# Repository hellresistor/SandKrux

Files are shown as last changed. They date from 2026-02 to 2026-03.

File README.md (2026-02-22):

# SandKrux

Placa de desenvolvimento baseada no chip **K210**, com entradas para **touch**, **câmera** e **LCD grande**, criada especificamente para rodar o firmware **Krux**.

## Status do projeto
**Em desenvolvimento — não finalizado.**  
Este repositório está em evolução. Mudanças podem ocorrer sem aviso.

## Foto da placa
Coloque a imagem em `docs/placa.jpg` (ou ajuste o caminho abaixo).

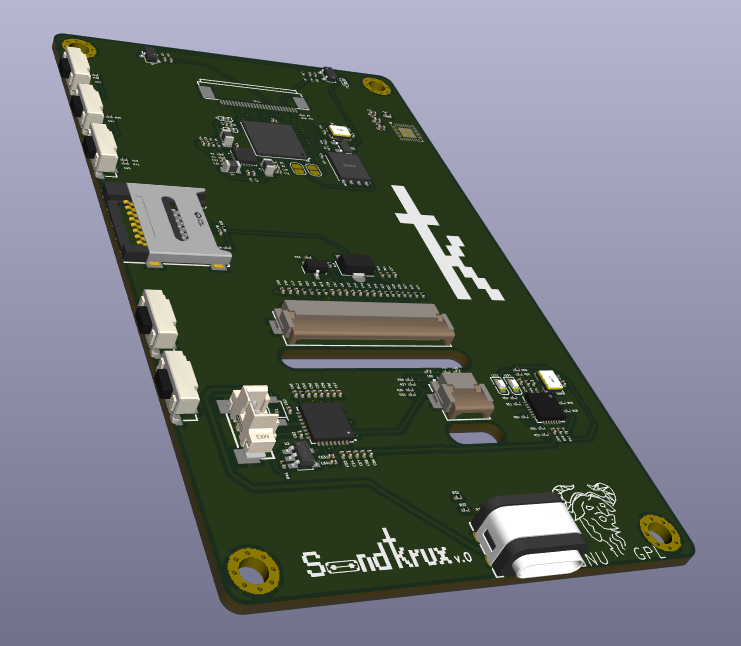
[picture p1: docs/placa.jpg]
Foto da placa


## Firmware alvo
Este hardware está sendo desenvolvido para o firmware Krux:
- https://github.com/selfcustody/krux

## Como colaborar
Contribuições da comunidade são muito bem-vindas.  
Abra issues, discuta melhorias e proponha alterações.

## Licença
GPLv3.

## Nota sobre fabricação e apoio ao Krux
Se no futuro você pretender **fabricar e vender** este dispositivo, fica o pedido de doar **ao menos 1%** do valor dos dispositivos para a equipe de desenvolvimento do Krux.  
Este é um projeto open-source e, sem o trabalho deles, nada disso existiria.

## Agradecimentos
Obrigado à comunidade e à equipe do Krux pelo trabalho que torna este projeto possível.

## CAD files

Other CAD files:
LIB_SandKrux/LIB_FH12-40S-0.5SH_55_/FH12-40S-0.5SH_55_/Allegro/fh1240s05sh55.psm
LIB_SandKrux/LIB_FH12-40S-0.5SH_55_/FH12-40S-0.5SH_55_/DEHDL/fh12_40s_0.5sh_55_/chips/chips.prt

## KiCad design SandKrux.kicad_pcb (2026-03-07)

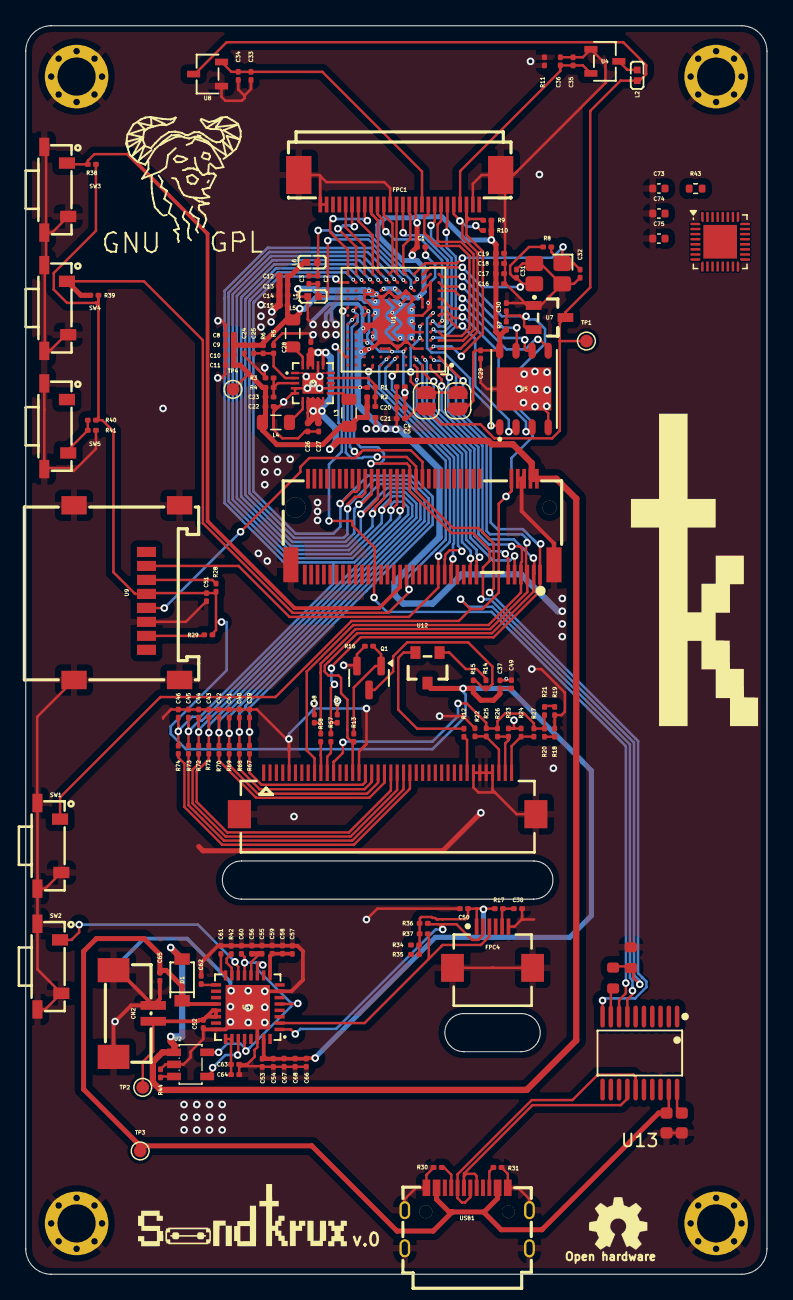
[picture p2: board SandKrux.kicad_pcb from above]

Board: 2 copper layers, 58.3 x 98.2 mm, 170 parts (0 on the bottom side), 115 nets.

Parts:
C1, C60, C62: 1uF; C_0201_0603Metric
C2, C4, C5, C6, C7, C18, C19, C29, C30, C34, C38, C49, C56: 100nF; C_0201_0603Metric
C3, C8, C9, C10, C11, C12, C13, C14, C15, C16, C17, C33, C36, C37, C50, C51, C53, C55, C58, C65: 10uF; C_0201_0603Metric
C20, C23, C25: 18pF; C_0201_0603Metric
C21, C22, C24, C26, C27, C28, C35, C52, C57, C59, C64, C66, C67, C68: 22uF; C_0201_0603Metric
C31, C32: 6pF; C_0201_0603Metric
C39, C40, C41, C42, C43, C44, C45, C46, C47, C48: 100pF; C_0201_0603Metric
C54: 1nF; C_0201_0603Metric
C61: 220uF; C_0201_0603Metric
C63: 220nF; C_0201_0603Metric
C73, C74, C75: 100n; C_0402_1005Metric
C77: 22uF; C_0603
C79: 10uF; C_0603
CN2: 1.25mm-2P socket; CONN-SMD_1.25T-2P
D1: 1N5819HW-7-F; SOD-123_L2.7-W1.6-LS3.7-RD
FPC1: 05A20L26P; FPC-SMD_05A20L26P
FPC3: FH12-40S-0.5SH(55); FPC-SMD_FH12-40S-0.5SH-55
FPC4: FH12-6S-0.5SH(55); FPC-SMD_FH12-6S-0.5SH-55
H1, H2, H3, H4: Hole, 3mm
IC1: TROPIC01_chip; QFN-32-1EP_4x4mm_P0.4mm_EP2.65x2.65mm
JP1, JP2: SolderJumper_2_Open; SolderJumper-2_P1.3mm_Open_RoundedPad1.0x1.5mm
L1, L2, L6: CBW100505U601T; L0402
L3, L4, L5: 2.2uH; L_0805_2012Metric
Q1: S8050; Q_SOT-23
R1, R6: 300k 1%; R_0201_0603Metric
R2, R3, R5: 150k 1%; R_0201_0603Metric
R4: 680k 1%; R_0201_0603Metric
R7: 12K; R_0201_0603Metric
R8: 1M; R_0201_0603Metric
R9, R10: 2K; R_0201_0603Metric
R11, R18, R21, R41: 0R; R_0201_0603Metric
R12: 5.1R; R_0201_0603Metric
R13, R14, R57, R58, R67, R68, R69, R70, R71, R72, R73, R74: 100R; R_0201_0603Metric
R15, R16, R17, R28, R29, R44: 10K; R_0201_0603Metric
R19, R20, R22, R23, R27, R40: NC; R_0201_0603Metric
R24, R25, R26, R30, R31: 5.1K; R_0201_0603Metric
R32, R33: 1kΩ; R_0603
R34, R35, R36, R37, R38, R39: 1.5K; R_0201_0603Metric
R42: 200K; R_0201_0603Metric
R43: 47k; R_0402_1005Metric
SW1, SW2, SW3, SW4, SW5: TL3330AF130QG; SW-SMD_E-SWITCH_TL3330
Sign_OSHW_7.3x6.0mm: Sign_OSHW_7.3x6.0mm; Sign_OSHW_7.3x6.0mmn
TP1, TP2, TP3, TP4: TestPoint_Small; TestPoint_Pad_D1.0mm
U1: K210_C913414; BGA-144_L8.0-W8.0-R12-C12-P0.65-BL
U2: MT9700; SOT-23-5_L3.0-W1.7-P0.95-LS2.8-BR
U3: XC6206-3.3V; SSOT-3_L2.9-W1.6-P0.95-LS2.8-BR
U4: XC6206P182MR_C347373; SOT-23-3_L3.0-W1.7-P0.95-LS2.9-BR
U5: GD25LQ128EWIGR; WSON-8_L6.0-W5.0-P1.27-BL-EP
U6: TMI7003C; QFN-20_L3.0-W3.0-P0.40-BL-EP1.7
U7: SGM803-TXN3/TR_C5152602; SOT-23-3_L2.9-W1.5-P1.90-LS2.6-BR
U8: XC6206P302MR_C347375; SOT-23-3_L3.0-W1.7-P0.95-LS2.9-BR
U9: HX TF-CARD XG8P H1.5; TF-SMD_HX-TF-CARD-XG8P-H1.5
U10: AXP173_C3345106; QFN-32_L5.0-W5.0-P0.50-TL-EP3.5-1
U12: PCIE-67P42H; PCIE-SMD_75P-P0.50_HYC01B-05NGFF-420
U13: CH552T; TSSOP-20_L6.5-W4.4-P0.65-LS6.4-BL
USB1: HYCW412-USBC16-065B; USB-C-SMD_HYCW412-USBC16-065B
X1: X322526MMB4SI; CRYSTAL-SMD_4P-L3.2-W2.5-BL

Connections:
+3.3V: C4.2, C5.2, C6.2, C7.2, JP2.1 (A), L2.2, TP1.1, U1.C5 (VDDIO5B), U1.C7 (VDDIO4B), U1.C8 (VDDIO3B), U1.D10 (VDDIO2A), U1.G10 (VDDIO1A), U1.H10 (VDDIO0A), U7.3 (VCC), U8.3 (VIN)
/3V3: C37.1, C49.1, C50.1, C51.2, C53.2, C54.2, C66.2, C67.2, C68.2, FPC4.1, R15.2, R17.1, R28.2, R29.2, R34.2, R35.2, R36.1, R37.1, R38.1, R39.1, R40.2, U3.3 (VIN), U9.4 (VDD), U10.31 (DCDC1)
/5V: C26.2, C27.2, C28.2, D1.2 (A), U2.1 (VOUT), U6.7 (VIN2), U6.8 (EN2), U6.9 (EN1), U6.10 (VIN1), U6.16 (NC), U6.18 (EN3), U6.19 (VIN3), U12.2, U12.4
/5V_USB: C65.1, C79.1, D1.1 (K), TP3.1, U10.20 (ACIN), U13.19 (VCC/VDD), USB1.A4B9 (VBUS), USB1.B4A9 (VBUS)
/ADD_3V0: C57.2, C58.2, C59.2, U10.9 (LDO3)
/BOOT: U1.B12 (IO_16), U12.53, U13.8 (P1.1/T2EX/CAP2/TIN1/VBUS2/AIN0)
/CAPTOUCH_RST: C38.1, FPC4.5, R17.2
/CC1_2: R30.2, USB1.A5 (CC1)
/CC2_2: R31.2, USB1.B5 (CC2)
/CH552_P1.0: C30.2, R7.2, SW1.1, U1.M1 (~RESET), U7.2 (~RESET), U12.10, U13.7 (P1.0/T2/CAP1/TIN0)
/CH552_RX0: U1.H12 (IO_5), U12.40, U13.10 (P3.0/PWM1_/RXD)
/CH552_TX0: R32.1, U13.9 (P3.1/PWM2_/TXD)
/EXTEN: U2.4 (EN), U10.27 (EXTEN)
/I2C_SCL: FPC4.3, R37.2, U10.2 (SCK)
/I2C_SDA: FPC4.2, R36.2, U10.1 (SDA)
/I2S2_SDI: U1.A3 (IO_35), U12.11
/I2S2_SDOD: U1.B3 (IO_34), U12.9
/IM0: FPC3.38, R22.1, R25.1
/IM1: FPC3.39, R23.1, R26.1
/IM2: FPC3.40, R24.1, R27.1
/IPSOUT: C60.1, U2.5 (VIN), U10.5 (VIN2), U10.11 (LDOIN), U10.13 (APS), U10.28 (VIN1)
/ISET: R44.2, U2.3 (SET)
/ISP_RX: R32.2, R33.1, U1.H11 (IO_4), U12.42
/KEY1: R39.2, SW4.1, U1.A9 (IO_23), U12.43
/KEY2: R38.2, SW3.1, U12.45
/LCD_BACKLIGHT: R12.2, U3.2 (VOUT)
/LCD_CS: FPC3.9, U1.A2 (IO_36), U12.7
/LCD_D0: C39.1, R67.2, U1.L12 (SPI0_D0), U12.58
/LCD_D1: C40.1, R68.2, U1.L11 (SPI0_D1), U12.56
/LCD_D2: C41.1, R69.2, U1.L10 (SPI0_D2), U12.54
/LCD_D3: C42.1, R70.2, U1.L9 (SPI0_D3), U12.52
/LCD_D4: C43.1, R71.2, U1.L8 (SPI0_D4), U12.50
/LCD_D5: C44.1, R72.2, U1.L7 (SPI0_D5), U12.48
/LCD_D6: C45.1, R73.2, U1.L6 (SPI0_D6), U12.46
/LCD_D7: C46.1, R74.2, U1.L5 (SPI0_D7), U12.44
/LCD_DC: C48.1, R58.2, U1.B2 (IO_38), U12.5
/LCD_RST: FPC3.15, R13.1, U1.A1 (IO_37), U12.3
/LCD_WR: C47.1, R57.2, U1.B1 (IO_39), U12.1
/PIN21: U1.B4 (IO_32), U12.21
/PIN23: U1.A4 (IO_33), U12.23
/PWRON: SW2.1, U10.14 (PWRON)
/SPI1_CS_TF: U1.B7 (IO_26), U9.2 (CD/DAT3), U12.33
/SPI1_MISO: U1.G11 (IO_6), U9.5 (CLK), U12.38
/SPI1_MOSI: R28.1, U9.3 (CMD)
/USBDM: U13.15 (P3.7/UDM), USB1.A7 (DN1), USB1.B7 (DN2)
/USBDP: U13.14 (P3.6/UDP), USB1.A6 (DP1), USB1.B6 (DP2)
/USB_D+: U1.B6 (IO_28), U12.29
/USB_D-: U1.A6 (IO_29), U12.31
/VBAT: C52.2, CN2.1, TP2.1, U10.21 (BAT), U10.22 (BAT)
/VCC_1V83V3: FPC3.12, R20.2, R21.2, R25.2, R26.2, R27.2
/VCC_6: R18.1, R20.1
/VCC_7: R19.1, R21.1
/VDD: C55.1, C56.1, U10.12 (LDO4)
/k210/0V9: C8.2, C9.2, C10.2, C11.2, C12.2, C13.2, C14.2, C15.2, C20.2, C21.2, C22.2, C23.2, C24.2, C25.2, L3.1, L4.1, L5.1, L6.2, R2.1, R4.1, R6.1, TP4.1, U1.D4 (VDD), U1.D6 (VDD), U1.D9 (VDD), U1.E7 (VDD), U1.E9 (VDD), U1.F4 (VDD), U1.F6 (VDD), U1.G7 (VDD), U1.G9 (VDD), U1.H4 (VDD), U1.H6 (VDD), U1.J5 (VDD), U1.J7 (VDD), U1.J9 (VDD)
/k210/1V8: C1.1, C16.2, C17.2, C18.2, C19.2, C29.1, FPC1.11, JP1.2 (B), R7.1, R9.2, R10.2, U1.H3 (VDDIO18), U1.J3 (VDDOTP), U1.K6 (VDDIO18), U1.K8 (VDDIO18), U5.8 (VCC)
/k210/26M_OUT: U1.L3 (OSC_CLK), U1.M2 (CLK)
/k210/CMOS-AVDD: C35.2, C36.2, FPC1.4, U4.2 (VOUT)
/k210/CMOS-DVDD: C33.2, C34.2, FPC1.10, U8.2 (VOUT)
/k210/DVP_D0: FPC1.19, U1.M12 (DVP_D0)
/k210/DVP_D1: FPC1.21, U1.M11 (DVP_D1)
/k210/DVP_D2: FPC1.22, U1.M10 (DVP_D2)
/k210/DVP_D3: FPC1.20, U1.M9 (DVP_D3)
/k210/DVP_D4: FPC1.18, U1.M8 (DVP_D4)
/k210/DVP_D5: FPC1.16, U1.M7 (DVP_D5)
/k210/DVP_D6: FPC1.14, U1.M6 (DVP_D6)
/k210/DVP_D7: FPC1.12, U1.M5 (DVP_D7)
/k210/DVP_HSYNC: FPC1.9, U1.E1 (IO_45)
/k210/DVP_PCLK: FPC1.17, U1.F1 (IO_47)
/k210/DVP_PWDN: FPC1.8, U1.E2 (IO_44)
/k210/DVP_RST: FPC1.6, U1.D2 (IO_42)
/k210/DVP_SCL: FPC1.5, R10.1, U1.C1 (IO_41)
/k210/DVP_SDA: FPC1.3, R9.1, U1.C2 (IO_40)
/k210/DVP_VSYNC: FPC1.7, U1.D1 (IO_43)
/k210/DVP_XCLK: FPC1.13, U1.F2 (IO_46)
/k210/F_CLK: U1.K1 (F_CLK), U5.6 (SCLK)
/k210/F_CS: U1.G2 (F_CS), U5.1 (~CS)
/k210/F_D0: U1.J1 (F_D0), U5.5 (SI(IO0))
/k210/F_D1: U1.G1 (F_D1), U5.2 (SO(IO1))
/k210/F_D2: U1.H1 (F_D2), U5.3 (WP#(IO2))
/k210/F_D3: U1.L1 (F_D3), U5.7 (HOLD#(IO3))
/k210/Vadj: C20.1, R1.1, R2.2, U6.14 (FB1)
/k210/Vb: JP1.1 (A), JP2.2 (B), U1.D3 (VDDIO6C), U1.F3 (VDDIO7C)
/k210/XIN: C32.2, R8.2, U1.M4 (XTAL_IN), X1.1 (OSC)
/k210/XOUT: C31.1, R8.1, U1.M3 (XTAL_OUT), X1.3 (OSC)
GND: C1.2, C4.1, C5.1, C6.1, C7.1, C8.1, C9.1, C10.1, C11.1, C12.1, C13.1, C14.1, C15.1, C16.1, C17.1, C18.1, C19.1, C21.1, C22.1, C24.1, C26.1, C27.1, C28.1, C29.2, C30.1, C31.2, C32.1, C33.1, C34.1, C35.1, C36.1, C37.2, C38.2, C39.2, C40.2, C41.2, C42.2, C43.2, C44.2, C45.2, C46.2, C47.2, C48.2, C49.2, C50.2, C51.1, C52.1, C53.1, C54.1, C55.2, C56.2, C57.1, C58.1, C59.1, C60.2, C61.2, C62.2, C63.2, C64.2, C65.2, C66.1, C67.1, C68.1, C73.1, C74.1, C75.1, C77.2, C79.2, CN2.0, CN2.2, FPC1.2, FPC1.15, FPC1.25, FPC1.26, FPC1.27, FPC1.28, FPC3.5, FPC3.16, FPC3.34, FPC3.35, FPC3.36, FPC3.37, FPC3.41 (MH1), FPC3.42 (MH2), FPC4.6, FPC4.7, FPC4.8, H1.1, H2.1, H3.1, H4.1, L1.2, Q1.2 (E), R1.2, R3.2, R5.2, R11.1, R11.2, R16.1, R18.2, R19.2, R22.2, R23.2, R24.2, R30.1, R31.1, R33.2, R41.2, R42.1, R44.1, SW1.2, SW1.3, SW1.4, SW2.2, SW2.3, SW2.4, SW3.2, SW3.3, SW3.4, SW4.2, SW4.3, SW4.4, SW5.3, SW5.4, U1.C3 (VSS), U1.C4 (VSS), U1.C6 (VSS), U1.C9 (VSS), U1.C10 (VSS), U1.D5 (VSS), U1.D7 (VSS), U1.D8 (VSS), U1.E3 (VSS), U1.E4 (VSS), U1.E5 (VSS), U1.E6 (VSS), U1.E8 (VSS), U1.E10 (VSS), U1.F5 (VSS), U1.F7 (VSS), U1.F8 (VSS), U1.F9 (VSS), U1.F10 (VSS), U1.G3 (VSS), U1.G4 (VSS), U1.G5 (VSS), U1.G6 (VSS), U1.G8 (VSS), U1.H2 (VSS), U1.H5 (VSS), U1.H7 (VSS), U1.H8 (VSS), U1.H9 (VSS), U1.J2 (VSS), U1.J4 (VSS), U1.J6 (VSS), U1.J8 (VSS), U1.J10 (VSS), U1.K2 (VSS), U1.K3 (VSS), U1.K5 (VSS), U1.K7 (VSS), U1.K9 (VSS), U1.K10 (VSS), U1.L2 (VSS), U2.2 (GND), U4.1 (VSS), U5.4 (VSS), U5.9 (EP), U6.1 (NC), U6.4 (NC), U6.5 (NC), U6.12 (NC), U6.13 (NC), U6.15 (NC), U6.17 (NC), U6.21 (EP), U7.1 (GND), U8.1 (VSS), U9.6 (VSS2), U9.9 (GND), U9.10 (GND), U9.11 (GND), U9.12 (GND), U10.7 (PGND2), U10.24 (TS), U10.30 (PGND1), U10.33 (EP), U12.6, U12.8, U12.76, U12.77, U13.18 (GND/VSS), USB1.13, USB1.14, USB1.15, USB1.16, USB1.A1B12 (GND), USB1.B1A12 (GND), X1.2 (GND), X1.4 (GND)
unnamed: C63.1, C64.1, U10.25 (IPSOUT), U10.26 (IPSOUT)
unnamed: FPC3.10, R58.1
unnamed: FPC3.11, R57.1
unnamed: FPC3.17, R67.1
unnamed: FPC3.18, R68.1
unnamed: FPC3.19, R69.1
unnamed: FPC3.20, R70.1
unnamed: FPC3.21, R71.1
unnamed: FPC3.22, R72.1
unnamed: FPC3.23, R73.1
unnamed: FPC3.24, R74.1
unnamed: FPC3.33, R12.1
unnamed: Q1.1 (B), R13.2, R16.2
unnamed: Q1.3 (C), R14.1, R15.1
unnamed: R40.1, R41.1, SW5.2
unnamed: C2.2, C3.2, L6.1, U1.L4 (VDDPLL)
unnamed: C2.1, C3.1, L1.1, U1.K4 (VSSPLL)
unnamed: R14.2, U3.1 (VSS)
unnamed: L2.1, U4.3 (VIN)
unnamed: C23.1, R3.1, R4.2, U6.3 (FB2)
unnamed: C25.1, R5.1, R6.2, U6.2 (FB3)
unnamed: L3.2, U6.11 (SW1)
unnamed: L4.2, U6.6 (SW2)
unnamed: L5.2, U6.20 (SW3)
unnamed: R29.1, U9.7 (DAT0)
unnamed: R42.2, U10.15 (BIAS)
unnamed: C62.1, U10.17 (VINT)
unnamed: C61.1, U10.16 (VREF)
unnamed: C77.1, U13.20 (V33)
VCC: C73.2, C74.2, C75.2, R43.2

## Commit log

2026-02-08 K210 E SISTEMAS DE ENERGIA DO MODULO PRINCIPAL
    [SandKrux.kicad_pcb, SandKrux.kicad_sch]
2026-02-10 pcb update lcd e toutch
    [SandKrux.kicad_pcb]
2026-02-11 TFT CARD
    [SandKrux.kicad_pcb, SandKrux.kicad_sch]
2026-02-11 usb ports
    [SandKrux.kicad_pcb, SandKrux.kicad_sch]
2026-02-15 AXP173 batery module
    [SandKrux.kicad_pcb, SandKrux.kicad_sch]
2026-02-16 organizacao de componentes, logo, vias e rotas de cirquitos de energia TROPIC01_chip
    [SandKrux.kicad_pcb, SandKrux.kicad_sch, untitled.kicad_sch]
2026-02-17 vias e rotas de componentes + atualizacao de logo
    [SandKrux.kicad_pcb, untitled.kicad_sch]
2026-02-19 detalhamento do PCIE-67P42H
    [SandKrux.kicad_pcb, untitled.kicad_sch]
2026-02-22 posicionamento de vias e tracos entre os componentes
    [SandKrux.kicad_pcb, SandKrux.kicad_sch, untitled.kicad_sch]
2026-02-23 m2 conector diagrama na placa principal
    [SandKrux.kicad_pcb, SandKrux.kicad_sch, untitled.kicad_sch]
2026-02-27 lcd and bottons conection on board
    [SandKrux.kicad_pcb, SandKrux.kicad_sch]
2026-02-28 test points and traces distribution
    [SandKrux.kicad_pcb, SandKrux.kicad_sch, untitled.kicad_sch]
2026-03-07 lib linux
    [SandKrux.kicad_pcb]
